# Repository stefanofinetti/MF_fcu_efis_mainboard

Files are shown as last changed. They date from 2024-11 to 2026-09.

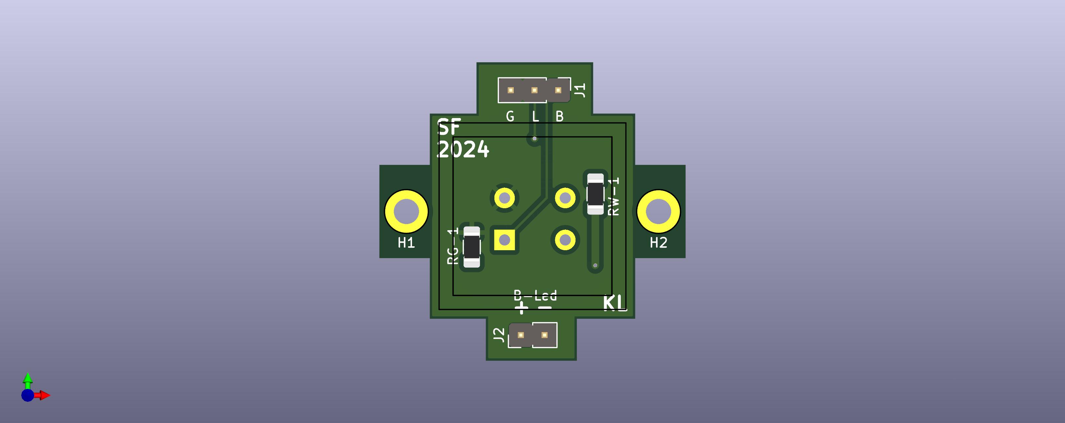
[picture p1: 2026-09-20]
Korry_Large/KorryLargePCB_SMD.jpg

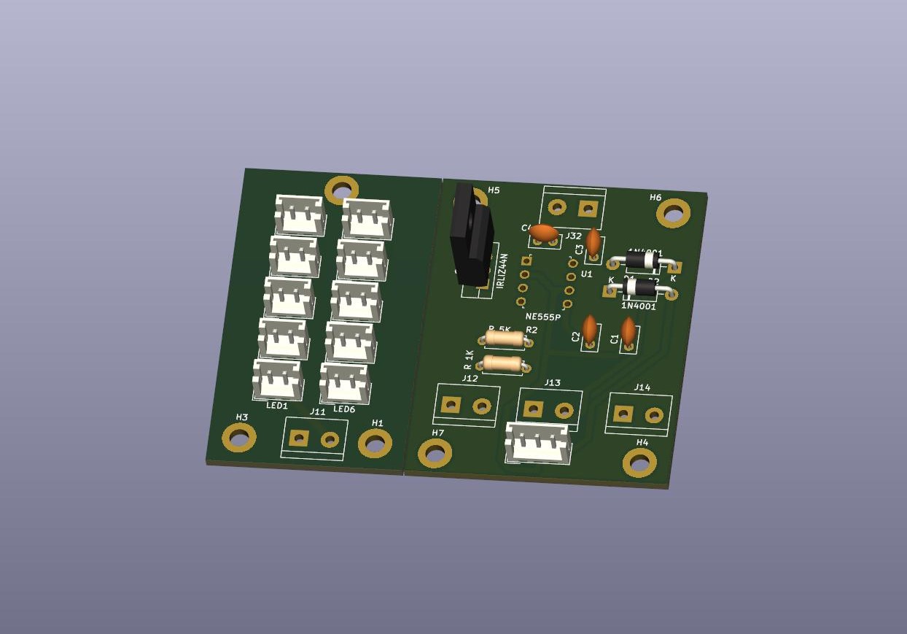
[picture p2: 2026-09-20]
Backlighting_Dimmer/Backlighting_PCB.jpg

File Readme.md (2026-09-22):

# A320 Glareshield — FCU + EFIS

This repository contains the complete glareshield unit: the FCU in the centre
and the two EFIS control panels either side, driven by
[MobiFlight](https://www.mobiflight.com/). The two outer side panels are not
built — three rarely used buttons did not justify the plastic.

The unit sits on a desk, is powered by its own mains adapter and connects to
the PC over USB, so it can be unplugged and moved.

* STL Files for 3D Printing, along with the .3mf files for multicolor printing
* SKP Files from SketchUp, if you want to edit dimensions or change anything
* Kicad files for editing the PCBs or changing components

## Features
- If you decide to not modify anything, you can just print the various 3D components and order the PCBs from JLCPCB.
- You will need a lot of materials, if you open the Kicad Projects you can obtain the BOM directly from them.
- You will need to build your own custom firmware (source provided) or you can use the one in the ZIP file inside the \_dist directory in VsCode Files

---

## Boards

| Folder | Project | Qty | Role |
|---|---|---|---|
| `Mainboard/` | `FCU_Mainboard_v3` | 1 | ATmega2560 + CH340G, 7 OLEDs behind a PCA9548A I²C mux, 4× CD74HC4067 analogue mux for the buttons, 20 annunciator outputs, TPS2115A supply selector. 270 × 100 mm, 2 layers |
| `PSU/` | `9V_Distribution` | 1 | 70 × 80 mm. Two independent regulators off one 9 V input: an LM2596S-5 buck for the backlighting and a P78A05-1000 for the mainboard. See *PSU revision* below |
| `Backlighting_Dimmer/` | `Backlighting_PCB` | 1 | NE555 PWM dimmer, potentiometer controlled, IRLIZ44N low-side switch, three outputs |
| `Backlighting_LEDModule/` | `Backlighting_LEDModule_PCB` | 3 | Passive fan-out: one input → twenty 2-pin outputs. Three of them only to keep the LED strip wiring short |
| `Korry_Large/` | `KorryLargePCB_SMD` | — | Tactile switch + green annunciator LED + white backlight LED |
| `Korry_Small/` | `KorrySmallPCB_SMD` | — | Same, smaller outline |

## Power architecture

```
 mains adapter 9 V / 3 A
        │
        └──► PSU  J1 ──► D1 ──┬──► F2 ──► LM2596S-5 ──► L1 ──┬──► 5 V ──┬──► J2 ─┐
                              │   (2 A)     D2 ◄──┘          │          ├──► J3 ─┤
                              │             catch      C2 ‖ C4          └──► J4 ─┤
                              │                                                  │
                              └──► F3 ──► P78A05-1000 ──► J5 ──► Mainboard J13    │
                                 (0.5 A)   C5‖C6  C7‖C8                  │        │
                                                                     IN1 ▼        │
 PC ──USB──► Mainboard P1 ──► VBUS ──────────────► IN2 ──► U8 TPS2115A            │
   (powered USB3 hub)                                         OUT ──► +5V         │
        │                                                                         │
        └──► 20 × Korry  (green annunciator LED + button)                         │
                   │                                                              │
                   │                            Backlighting_Dimmer ◄─────────────┘
                   │                                    │
                   │                                    └──► 3 × LEDModule
                   └──────────── white backlight LED ◄───────────┘
                                 + 6 LED strip segments
```

Two supply chains that share only ground. The backlighting, which draws the
real current, runs off the mains adapter through the buck. The mainboard takes
whichever of the two is available: `U8` picks the adapter through `J13`
whenever it is plugged in and falls back to USB when it is not — see
*Mainboard selector*.

## Interconnect

**Every cable in the unit is straight through: pin 1 to pin 1.** It was not
always so, and the boards still carry the marks that say which pin is which,
so you can check rather than trust this page.

### Mainboard → Korry (`BTN+LED`, 3-pin)

| pin | Signal | Marked |
|---|---|---|
| 1 | GND | `GND` on the mainboard, `G` on the Korry |
| 2 | annunciator LED, driven by an MCU pin through the 220 Ω on the Korry board | `LED` / `L` |
| 3 | button to GND, read through a CD74HC4067 | `BTN` / `B` |

### LEDModule → Korry (`BK_LED`, 2-pin)

| pin | Signal | Marked |
|---|---|---|
| 1 | +5 V | `+` on the odd row of the LEDModule, `+` on the Korry |
| 2 | switched return, through the 91 Ω on the Korry board | `-` |

### Backlighting_Dimmer → LEDModule (`BOARD_CONN`, screw terminal)

| pin | Signal |
|---|---|
| 1 | +5 V, always present |
| 2 | return, switched to GND by the IRLIZ44N |

The dimmer's three outputs are marked `TO LEDMODULE`, the LEDModule's input
`5V IN`, and both have a `+` and a `-` next to the screws.

### PSU → consumers

`J2`, `J3` and `J4` are three taps on one node, not three independent lines.
There is no per-output fusing. Protection is per *branch*, not per output:
`F2` (2 A) covers everything downstream of the buck, `F3` (0.5 A) covers the
mainboard regulator, and a fault on one cannot take the other down.

## Current budget

Calculated where the resistors are known, estimated elsewhere.

| Load | Rail | Current |
|---|---|---|
| 7 OLEDs | +3V3, from +5V through the AMS1117 | 105–140 mA |
| Green annunciators, 11 lit worst case (220 Ω) | driven by MCU pins | ~130 mA |
| ATmega2560 + CH340G + muxes + power LED | VIN / +5V | ~55 mA |
| **Mainboard total, from USB** | | **290–340 mA** |
| 20 white backlight LEDs (91 Ω) | backlight 5 V | 418 mA |
| 6 LED strip segments, 3528 | backlight 5 V | 360–720 mA |
| **Backlighting total, from the adapter** | | **780–1140 mA** |

The adapter supplies 27 W and the unit uses under 7 W. Nothing is binding any
more: `F2` was the constraint when it was a 1 A part, which derated to under
0.8 A of hold current against the 0.75 A the buck actually draws. At 2 A it
has margin to spare.

## PSU revision

The 9 V distribution board was reworked.

| Change | Why |
|---|---|
| **`D2` added** — 1N5822, cathode on the switch node, anode to ground | A non-synchronous buck has nowhere for the inductor current to go when the switch opens. Without an external diode it freewheels through the substrate diode of the LM2596 itself: roughly 0.4 W of extra dissipation inside the package on top of its own 0.7 W, and substrate injection the part is not specified for. This is why the board works and why it degrades |
| **`C4` added** — 220 µF radial electrolytic in parallel with `C2` | The LM2596 control loop needs some ESR on the output, and `C2` was a ceramic with almost none. `C2` has since become an electrolytic too, so the two now share the job. The RMP V5, same family of design but with electrolytics at its regulator, has never misbehaved |
| **`F2` 1 A → 2 A** (`MF-RHT100` → `MF-RHT200`) | At 1.14 A out the input draws about 0.75 A. Derated for the temperature inside a printed case, a 1 A polyfuse holds under 0.8 A — too close to nuisance tripping. Pads are identical, so the swap costs nothing in layout |
| **Power section re-laid out** | `U4` pin 2, the cathode of `D2` and pin 1 of `L1` now sit on one straight line at y = 64.95, and `C1` sits 4 mm under the VIN pin. The commutation loop went from *nonexistent* to about 4 mm of forward track each side |

### Through-hole where it helps

`D1`, `D2`, `C1` and `C2` were SMD; they are now through-hole. Two of those
four are not a convenience:

* `C1` sits across the 9 V input and needs 25 V of rating. A 1206 MLCC of
  that capacitance does not exist at 25 V, so the part was always going to be
  under-rated and to lose most of its capacitance to DC bias. As a radial
  electrolytic the problem simply goes away.
* `C2` is the buck's output capacitor, and the LM2596 wants some ESR there.
  As a ceramic it had almost none, which is why `C4` was added; as an
  electrolytic it provides it itself.

`D1` and `D2` are 1N5822, 40 V 3 A, which is generous against the ~1 A each
actually carries. `D2` is mounted vertically on a 5.08 mm pitch, shorter than
the 6.8 mm of the SMC it replaces, so the commutation loop got slightly
tighter rather than longer.

Everything in the buck section is now through-hole except `U4`, whose tab
needs the copper pour to dissipate, and the status LEDs with their resistors.
A useful side effect: every ground pad in that section now passes through the
board and reaches both planes on its own, so four stitching vias and their
stubs are gone.

Component spacing was opened up at the same time. Nothing placed by hand is
closer than 2 mm to its neighbour now; the tightest pairs left on the board
are the original LED-and-resistor pairs at 0.66 mm.

### The mainboard branch

The mainboard needs a 5 V source that does not depend on the USB hub. It does
**not** take it from `J2`/`J3`/`J4`: those are one node with the backlighting
on it, PWM-switched by the dimmer's IRLIZ44N in steps of up to 1.1 A. Putting
the MCU and seven OLEDs on that rail would feed them those steps.

Instead a second, independent regulator, tapped from D1's cathode: the reverse
protection is shared, the fuse is not, so a fault on one branch cannot take
down the other. `F3` is 0.5 A for the branch's ~215 mA at 9 V. `U1` is the same
P78A05-1000 module used on RMP V5, with 100 nF + 100 uF each side as there.

The board grew from 50 × 70 to **70 × 80 mm** to make room. The whole
regulator chain lives in the new strip at x 150..170, so the buck section
keeps its original placement and its original routing, and every track stays
on the front: the bottom layer is an uninterrupted ground plane.

All 55 tracks are on the front, so the return current of each loop runs
directly beneath its outward track and the enclosed area stays small.
Stitching vias next to the ground terminals of `C1`, `C2`, `C4` and the anode
of `D2` are tied to their pads by short tracks rather than through the
thermal spokes.

The outline and the four mounting holes did move with the enlargement, so the
printed base has to be reprinted or its brass inserts moved. The positions of
`J1` to `J4` are unchanged, so the wiring loom stays as it is.

## Mainboard selector

`U8` is a TPS2115A power mux: `IN1` takes the clean 5 V from the PSU's `J5`,
`IN2` takes USB `VBUS`, and `OUT` becomes the board's `+5V`. `D0` is tied to ground and `D1` comes from a 100k/100k divider
on the incoming rail, which makes the choice deterministic rather than
"whichever input happens to be higher": the external supply wins whenever it
is above about 4 V, and the board falls back to USB below that.

The part has no body diodes across its switches, so nothing can flow back
into the USB port when the board runs on the adapter. `ILIM` is set to about
0.8 A by `R34`. `STAT` is left unconnected; it is an open-drain output that
goes low on `IN1`, if an indicator is ever wanted.

`P1` pin 1 and `R14`, the D+ pull-up, moved off `+5V` onto the new `VBUS`
net. `JP1`, `VCC` and the ISP path are untouched: `JP1` still chooses whether
`VIN` comes from the board rail or from the programmer.

The symbol lives in `Mainboard/TPS2115A.kicad_sym` with a project-local
`sym-lib-table`, so the repository is self-contained.

Counting tracks as well as footprints, the old 250 mm board had no free
rectangle big enough for the cluster anywhere near the power section, so the
board grew to **270 x 100 mm**: it gains 20 mm on the right and nothing that
already existed moves, apart from the two right-hand mounting holes, which go
from x 265 to x 285. The other five stay put. The 100 mm depth is untouched.

The whole selector sits in that new strip, in a column from `J13` at the top
down through `U8`, `C27` and the divider.

The cluster is routed and the board reports 0 violations, 0 unconnected items
and 0 parity issues.

The three power connections around the selector run at 1 mm, the width their
netclass asks for. They cannot run that wide the whole way: they leave pins
6, 7 and 8 of a TSSOP at 0.65 mm pitch, where the pad itself is only 0.4 mm
tall, so each stays at 0.4 mm for the three to six millimetres it travels
alongside the other two and widens as soon as they diverge. Series resistance
of the three paths, in 35 µm copper:

| Path | |
|---|---|
| `5V_EXT`, `J13` → `U8` pin 8 | 19 mΩ |
| `+5V`, `U8` pin 7 → `C27` | 13 mΩ |
| `VBUS`, `C26` → `U8` pin 6 | 13 mΩ |

The `5V_EXT` spine below y 55 and the tap to `R32` stay at 0.3 mm on purpose:
from there down only the `SEL` divider draws, which is microamps.

## Reading the boards

The silkscreen is meant to be enough on its own: every connector says what
plugs into it and every pin says what it carries, so you can wire the unit
with the boards in front of you and the schematic only for the details.

| Board | What is printed |
|---|---|
| `Mainboard` | the function on each connector (`APPR`, `R_FD`, `HDG_ENC`…) and, next to the pins, `GND` / `LED` / `BTN`, `L` / `R` on the encoders, `VOR` / `ADF`, `hPa` / `inHg`. `J13` carries `5V from PSU` with `GND` and `5V` on its two screws |
| `PSU` | `9V IN` on `J1`, `5V BACKLIGHT` on `J2`–`J4`, `5V MAINBOARD` on `J5`, and a `+` beside the live screw of every terminal |
| `Backlighting_Dimmer` | `5V IN` on the input, `TO LEDMODULE` on the three outputs, `Backlighting POT` on the potentiometer header |
| `Backlighting_LEDModule` | `5V IN` on the input, `+` and `-` beside its screws and beside both output rows |
| `Korry_Large` | `BTN+LED` and `BK_LED` on the two connectors, `G`, `L` and `B` beside pins 1, 2 and 3, `+` and `-` beside the backlight connector and beside each LED on the back, and the two resistor values, 220 and 91, which are otherwise identical parts |
| `Korry_Small` | the same, with `+5` and `L` on the backlight connector and a `+` beside each LED on the back |

Component values live on `F.Silkscreen`, not on `F.Fab`, so they reach the
board. Values are never edited to make a label: where a connector's value is
the name of the terminal block, the value stays where it is and a separate
piece of text carries the meaning.

## Known issues

None open.

## Libraries you will need

All six projects are KiCad 10. Every board reports 0 unconnected items and 0
schematic parity issues, but ERC and DRC still flag missing libraries: the
symbols are embedded in the files so nothing is lost, only the links dangle.
Install these from the Plugin and Content Manager to clear them:

| Library | Used for |
|---|---|
| Alternate KiCad Library | the LED and Schottky footprints: `PCM_LED_AKL`, `PCM_LED_SMD_AKL`, `PCM_Diode_Schottky_AKL`, `PCM_Diode_SMD_AKL` |

That is the only one left. Three others used to be needed and are not any
more. The screw terminals are now `Connector:Screw_Terminal_01x02`, which
ships with KiCad. The two symbols that came from the Digi-Key library, the
NE555 on the dimmer and the tactile switch on `Korry_Large`, now live beside
their own projects:

| File | Symbol |
|---|---|
| `Mainboard/TPS2115A.kicad_sym` | the supply selector |
| `Backlighting_Dimmer/NE555P.kicad_sym` | the timer |
| `Korry_Large/1825910-6.kicad_sym` | the tactile switch |

Those are the symbols the boards were drawn with, not library equivalents,
which matters for the switch: `Switch:SW_Push_Dual` puts its pins in the same
places but numbers them 1-3 and 2-4 where this one numbers them 1-2 and 3-4,
so substituting it would change which pins are shorted inside the button.

Every board has had `Update Footprints from Library` run on it, so the
footprints are the KiCad 10 revisions and no `lib_footprint_mismatch`
remains. If you run it again, untick **Reset text layers and visibilities**
and **Reset text effects**, or every component value goes back to `F.Fab`
and stops being printed.

What each board reports today, with all six at 0 unconnected items and 0
parity issues:

| Board | DRC | ERC |
|---|---|---|
| `Mainboard` | clean | clean |
| `PSU` | clean | clean |
| `Backlighting_Dimmer` | clean | clean |
| `Backlighting_LEDModule` | clean | clean |
| `Korry_Large` | clean | clean |
| `Korry_Small` | clean | clean |

The dimmer carries one excluded violation, recorded in the project file: the
wire-entry drawing inside the `J32` footprint reaches within 0.02 mm of the
board edge, so two hundredths of a millimetre of ink do not get printed.
`J32` cannot move down — `C4` sits 0.04 mm under its courtyard and the
usable window is 10.49 mm tall for a 10 mm body — and the alternative was
editing the library footprint, which is worse than the complaint.

## Gotchas

- **Anything edited outside KiCad leaves the ground pour stale.** The stored
  fill is the one computed before the edit, and until you open the board and
  press `B` DRC invents clearance, hole and solder-mask violations that all
  name `Zone [GND]` and none of which are real. Every board here is committed
  with its zones freshly filled; if you edit the files by script, refill
  before generating production output.
- **If you ever run *Update Footprints from Library*, untick "Reset text
  layers and visibilities" and "Reset text effects".** Without that, every
  component value goes back to `F.Fab` and stops being printed.
- **`F8` in Pcbnew clears `exclude_from_pos_files` on the seven mounting
  holes**, which puts them into the pick-and-place file. Re-check before
  generating production output.
- Three 3D models are missing, and the KiCad package has nothing to stand in
  for them: the two Bourns polyfuses on the `PSU`, the toroid `L1` beside
  them, and `P1` on the mainboard. For the toroid the library carries only
  common-mode ones, which have four pins instead of two; for `P1` the four
  holes sit in a 2 x 2 pattern and every USB-A footprint KiCad ships puts its
  pins in a single row. Everything else on all six boards renders. A few are
  stand-ins of the same package rather than the same part number: the
  crystals use the Wuerth 12SMX, same 7.0 x 5.0 four-pin outline, and the
  P78A05 uses the RECOM R-78E, whose three pins sit on exactly the same
  2.54 mm pitch.
- Some tracks are narrower than their netclass and are meant to be. The two
  0.4102 mm segments on `+3V3` are the breakout from pad 24 of the PCA9548A,
  a 0.65 mm-pitch package whose pad is 0.41 mm tall: it is a dead-end spur
  2.35 mm long carrying the mux's own supply. Same story for the 0.4 mm
  necks at `U8` and the 0.5 mm spur to `U3` pin 24. Widening any of them
  breaks clearance and buys nothing.
- `VIN` has its own netclass with 0.1 mm clearance. Moving it to the `5V`
  class, which uses 0.2 mm, produces about 70 violations against existing
  copper.
- Production files are generated by the
  [Fabrication Toolkit](https://github.com/bennymeg/Fabrication-Toolkit)
  plugin and are not versioned.

---

## Getting Started
### Prerequisites
- Software required:
   * [KiCad](https://www.kicad.org/) — version 10 or later, the projects have been migrated
   * [SketchUp](https://www.sketchup.com)
   * [VsCode]
   * [MobiFlight]

- Any libraries or components used.

### Installation
1. Clone the repository:
   ```bash
   git clone https://github.com/stefanofinetti/MF_A320_Glareshield.git
   ```

## License

This code and all the items are release under GPLv3.0 license. Feel free to use as you wish as long as you redistribute the source code.
It would be nice a mention, though, if you use this work. I invested a good amount of hours just to make it for the amazing MobiFlight community.

Pull requests that fix any of the issues listed above are very welcome.

## Acknowledgements

 This project couldn't have seen the light without the excellent work, and kind support, of [GaGagu](https://github.com/gagagu) and [ElRal](https://github.com/elral). Their work is amazing, so please have a look at their repositories

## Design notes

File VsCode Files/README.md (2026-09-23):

# SF FCU — firmware

MobiFlight custom device that drives the seven OLED displays of an A320
FCU/EFIS panel: the five FCU windows and the two EFIS barometer displays.

Buttons, encoders and LEDs are plain MobiFlight and are configured in the
Connector. They do not go through this firmware.

## What this tracks

The reference is **MobiFlight's own scaffolding**: the project layout,
`platformio.ini`, the build scripts and `MFCustomDevice.*` follow
[MobiFlight/CommunityTemplate](https://github.com/MobiFlight/CommunityTemplate),
and `custom_core_firmware_version` is kept at the core firmware release the
template points to — currently **3.1.4**. `src/` is not in the repository;
`get_CoreFiles.py` clones the core on the first build.

The display code came from Gagagu's
[A320 EFIS/FCU display](https://github.com/gagagu/Mobiflight-A320-Efis-Fcu-Display-with-ESP32)
by way of [elral/MF_FCU_EFIS_OLEDs](https://github.com/elral/MF_FCU_EFIS_OLEDs)
v1.0.1. `FCU_EFIS.cpp`, `OLEDInterface.h` and the fonts are theirs. Following
elral is *not* a goal — following the MobiFlight core is.

## What differs from the template

| | |
|---|---|
| Device type | `SF_FCU`, so it installs alongside the upstream one |
| EFIS channels | left and right are the other way round from upstream |
| `SERIAL_RX_BUFFER_SIZE` | 256, not the template's 96 — see below |
| Targets | Mega only |

### Multiplexer channels

The seven displays hang off a PCA9548A, one display per channel:

| Channel | Display |
|---|---|
| 0 | EFIS right — barometer |
| 1 | EFIS left — barometer |
| 2 | SPD / MACH |
| 3 | HDG / TRK |
| 4 | HDG-V/S / TRK-FPA annunciator |
| 5 | ALT |
| 6 | V/S — FPA |

The channel numbers live in `FCU_EFIS.h`. Change them there if the displays
are wired to different channels.

### Serial receive buffer

A display update blocks the loop for roughly 28 ms — 5 ms of `delay()` for the
multiplexer switch plus a 1 KB frame at 400 kHz. At 115200 baud more than 300
bytes can arrive in that window, so the template's 96-byte receive buffer
would drop characters. Do not lower it.

### Footprint

The ATmega2560 has 8 KB of RAM and MobiFlight reserves most of it up front:
1600 bytes for the device arena (`MF_MAX_DEVICEMEM`) and 1000 for the input
names (`MEMLEN_NAMES_BUFFER`). Those two are sized for the Connector config,
not for this code, and are the wrong place to economise.

What this project does instead:

* **`build_unflags` turns off the device families the panel cannot have** —
  segment displays, character LCD, steppers, servos, analog inputs and both
  shift registers. Input multiplexers stay on; the panel uses them. Buttons,
  encoders and outputs are core and always present. This is worth 181 bytes
  of RAM and about 14 KB of flash. To get one back, delete its line.
* **No `String` anywhere.** The values from the Connector live in fixed
  buffers, so a redraw allocates nothing and the heap cannot fragment. The
  only allocation left in the whole firmware is Adafruit's 1 KB frame buffer,
  taken once at startup.

Static RAM actually rose by 18 bytes when the `String`s went, because nine
6-byte objects became nine 8-byte buffers. The point was never the 18 bytes:
it was that each of those objects also held a heap block, and three more were
allocated and freed on every single redraw.

## I2C address and display type

The custom device takes the address of the PCA9548A, which the multiplexer's
A0/A1/A2 pins set: all low is 0x70.

The address also picks the display driver, which is easy to miss:

* **even** address (0x70) → **SH1106**
* **odd** address (0x71) → **SSD1306**

So an SSD1306 needs the multiplexer strapped to an odd address and the custom
device set to match. The shipped `SF FCU.mfmc` is set to 0x70, i.e. SH1106.

## Building

PlatformIO installed through the VS Code extension does not put `pio` on the
PATH. Either open a terminal from the PlatformIO toolbar, or call it by its
full path, `%USERPROFILE%\.platformio\penv\Scripts\pio.exe`.

```
pio run -e SF_FCU_mega
```

That produces version `0.0.1`. For a real one set `VERSION` — the build
stamps it into both the firmware filename and `board.json`, which have to
agree or MobiFlight will not find the firmware. The version has to be an
environment variable, so the syntax differs per shell:

```
rem cmd.exe
rmdir /s /q _build _dist
set "VERSION=1.1.0" && pio run -e SF_FCU_mega
```

```
# PowerShell
Remove-Item -Recurse -Force _build, _dist -ErrorAction SilentlyContinue
$env:VERSION = "1.1.0"; pio run -e SF_FCU_mega
```

```
# bash, and what the GitHub workflow uses
rm -rf _build _dist
VERSION=1.1.0 pio run -e SF_FCU_mega
```

Deleting `_build` and `_dist` first is not optional: `copy_fw_files.py` only
stamps the version into `board.json` when `_build/` does not yet exist, so a
leftover folder ships the previous version's json.

The result is an installable ZIP in `_dist/`. Extract it into the `Community`
folder of your MobiFlight installation, then flash from the Connector.

`documents/` holds Gagagu's original drawings, kept for reference.

## Known gaps, inherited from upstream

* MessageID −1 (Connector closing) and −2 (power saving, after the 600 s in
  the `.mfmc`) are not handled, so the displays keep showing the last values
  instead of going dark. On OLEDs that is a burn-in risk.
* The Mach zero-padding in `updateDisplayFcuSpd()` writes past the end of the
  `String` and silently does nothing.
* The zero-padding elsewhere relies on `String::operator[]` returning a zeroed
  dummy when read out of range. It works, but on an implementation detail.

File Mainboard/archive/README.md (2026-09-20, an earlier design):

# Archived schematics

Files kept here are **not part of the FCU_Mainboard_v3 design**. They are not
referenced by the root sheet and are excluded from ERC, DRC, the netlist and
the BOM. Nothing in the fabricated board depends on them.

## backlighting.kicad_sch

Panel backlighting for the FCU + EFIS unit. It is **not connected to the
mainboard**: the backlight has its own dedicated circuitry and is not driven by
MobiFlight, so brightness cannot be controlled from the simulator.

Kept because the design may be revisited if backlight control is ever brought
under MobiFlight. If that happens it will be redesigned from scratch rather
than wired into the current board, so treat this file as a reference for the
existing circuit, not as a starting point.

## Removed, recoverable from git history

Two more orphan sheets were deleted rather than archived, both superseded
leftovers from v2:

- `EFIS.kicad_sch` — the v2 combined EFIS sheet. Its reference designators
  clash with the live sheets while meaning something else (J16 was
  `L_EFIS_FD`, it is now `R_FD`), and its global labels use an older naming
  scheme (`L_EFIS_FD_BTN`, `L_EFIS_RNG_160`, ...) that no longer exists.
  Superseded by `efis_left.kicad_sch` and `efis_right.kicad_sch`.
- `multiplexers.kicad_sch` — U3/U4 as CD74HC4067 breakout modules. The board
  now uses bare `74xx:CD74HC4067M` in SOIC-24W.

Both were removed in the commit that created this file; `git log --diff-filter=D
-- "Kicad Files/EFIS.kicad_sch"` will find them.

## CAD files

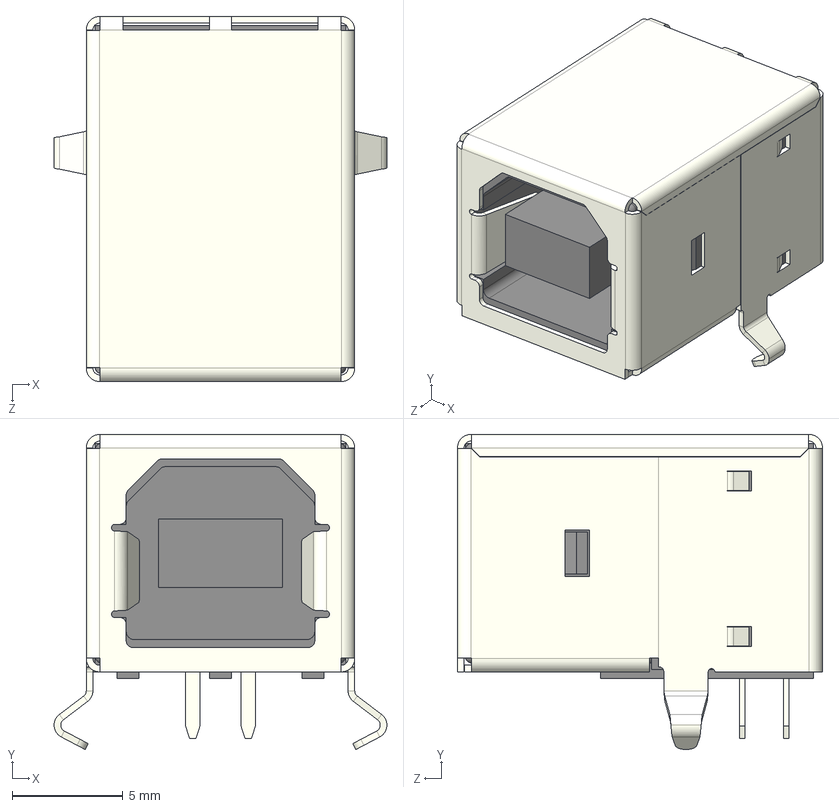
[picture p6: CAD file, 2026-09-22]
Mainboard/3dmodels/USB_B_SameSky_UJ2-BH-1-TH.step
15.0 x 14.2 x 16.5 mm

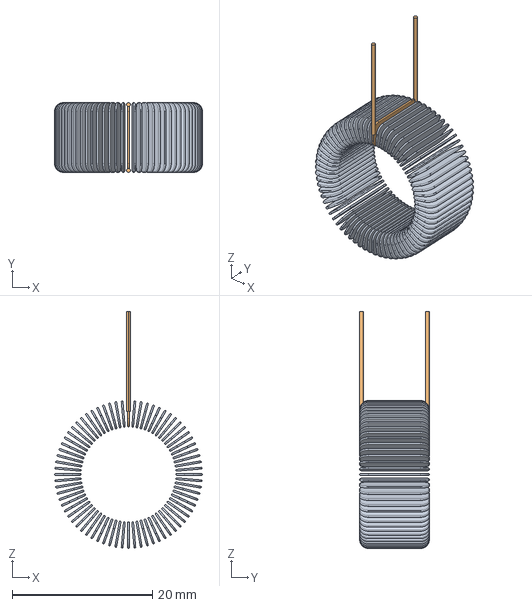
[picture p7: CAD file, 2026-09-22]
PSU/3dmodels/2100LL-1R0-V-RC.step
21.1 x 9.96 x 33.8 mm

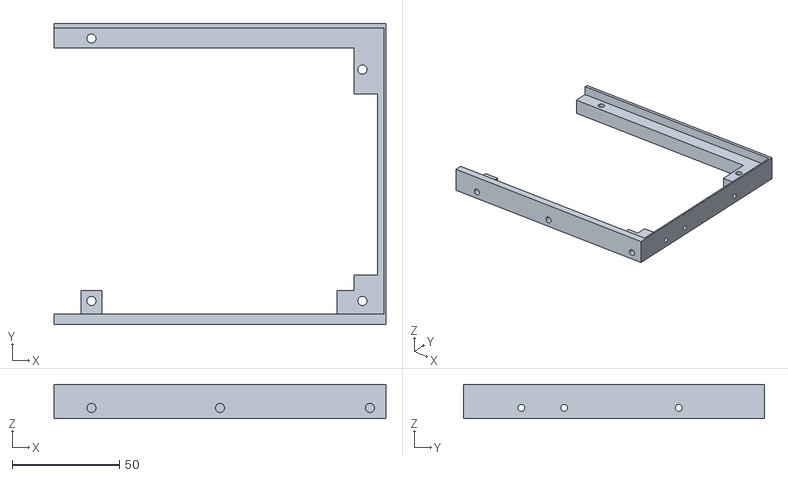
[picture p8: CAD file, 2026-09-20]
STL Files/Black/FCU_FRAME_RIGHT.stl
155.0 x 140.5 x 16.0

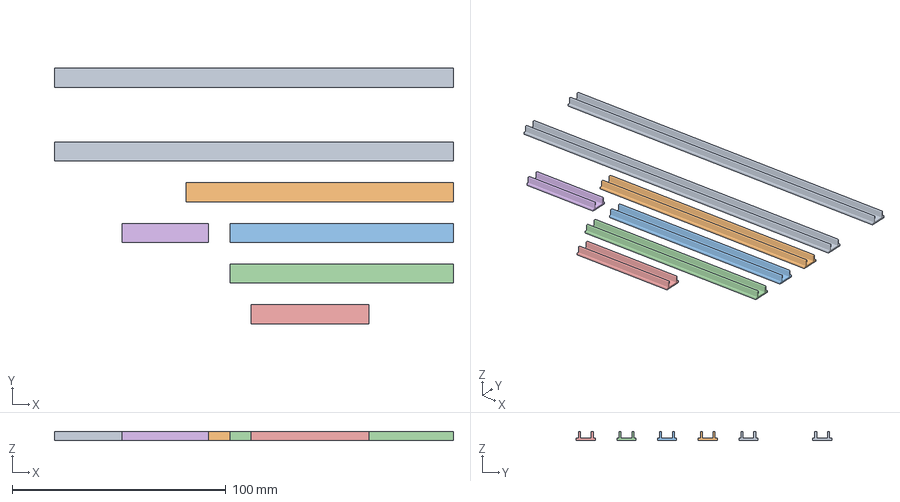
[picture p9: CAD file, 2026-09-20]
STL Files/FCU_LED_RAILS_COVER.3mf
186.5 x 119.5 x 4.00 mm
EFIS_LEFT_LED_RAILS_COVER.stl
FCU_LED_RAILS_COVER.stl_5
FCU_LED_RAILS_COVER.stl_3
FCU_LED_RAILS_COVER.stl_4
FCU_LED_RAILS_COVER.stl_1
FCU_LED_RAILS_COVER.stl_2

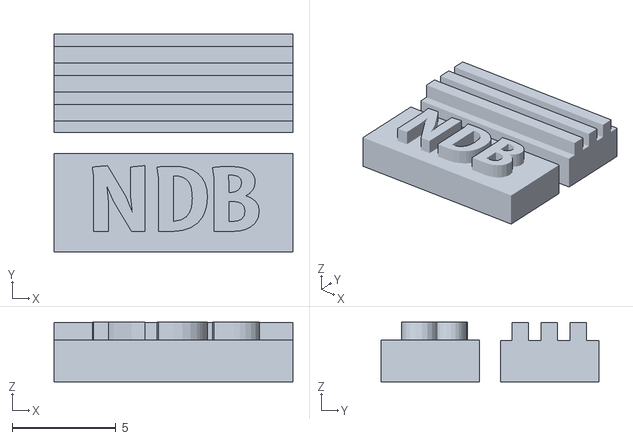
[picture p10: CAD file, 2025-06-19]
STL Files/Korry_19x16/NDB_transparent_V5.stl
11.5 x 10.5 x 2.88

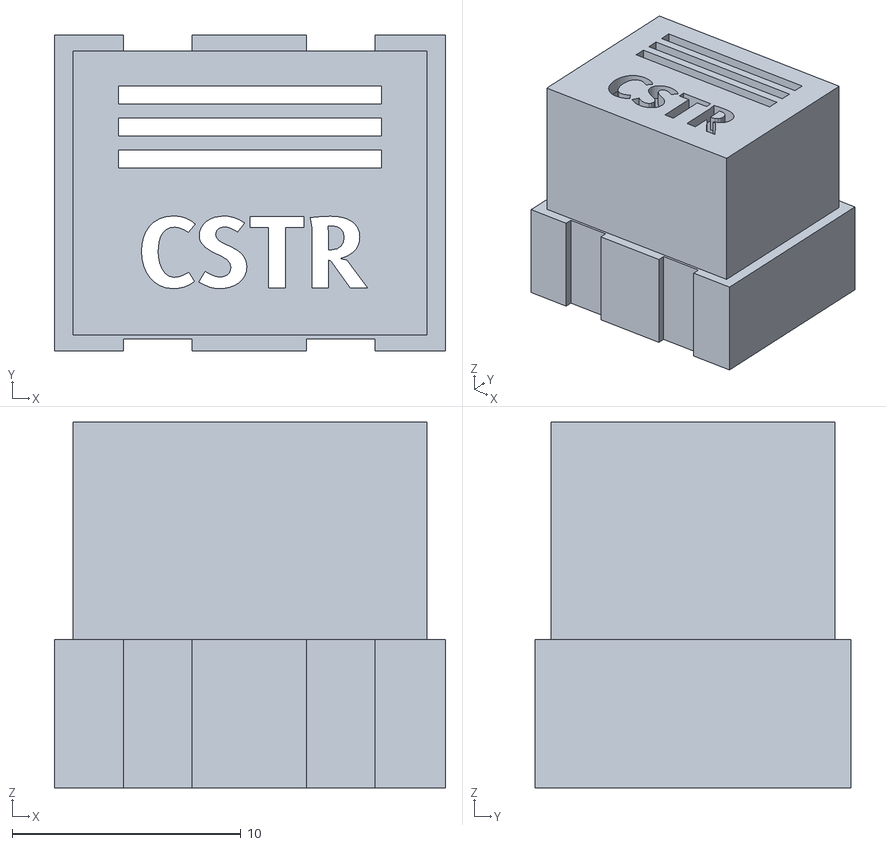
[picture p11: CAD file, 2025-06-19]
STL Files/Korry_19x16/V5/CSTR_BLACK.stl
17.1 x 13.8 x 16.0

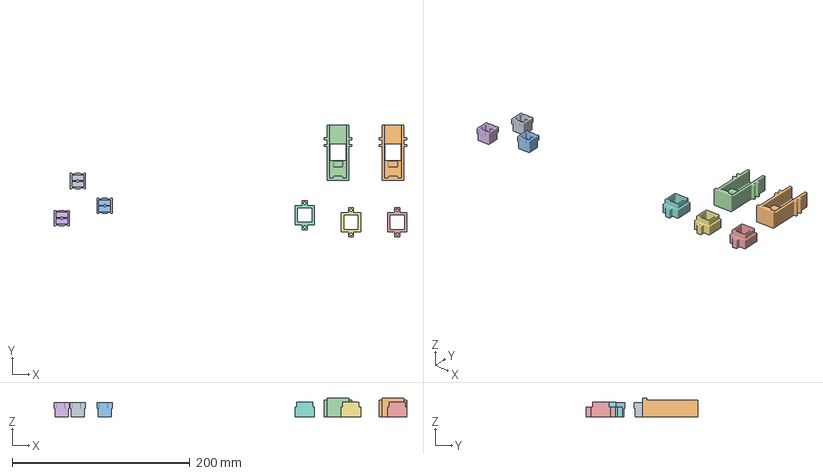
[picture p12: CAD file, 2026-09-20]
STL Files/Korry_19x19/Korry19x19_button.3mf
397.0 x 125.8 x 21.2 mm
AP1_button
Rotary_ALT_BARO_Outer_case.stl x 2
AP2_button
Korry19x19_case_v5.stl x 3
AT_button

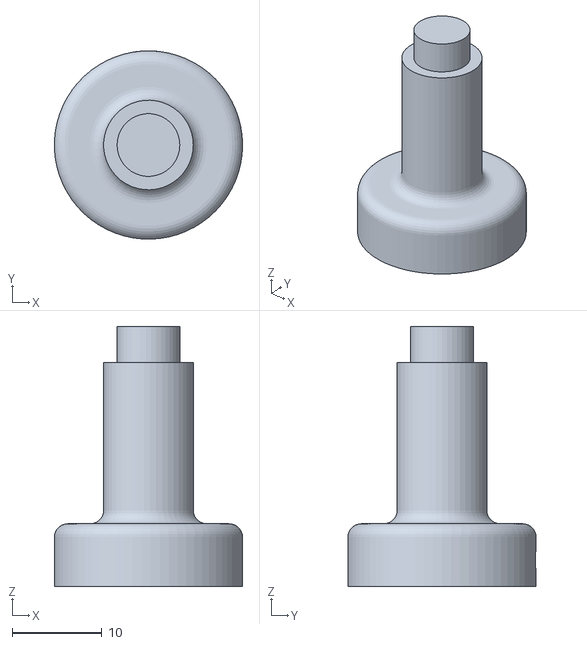
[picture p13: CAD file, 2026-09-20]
STL Files/Rotaries/SpeedKnob_Base.stl
21.0 x 21.0 x 29.0

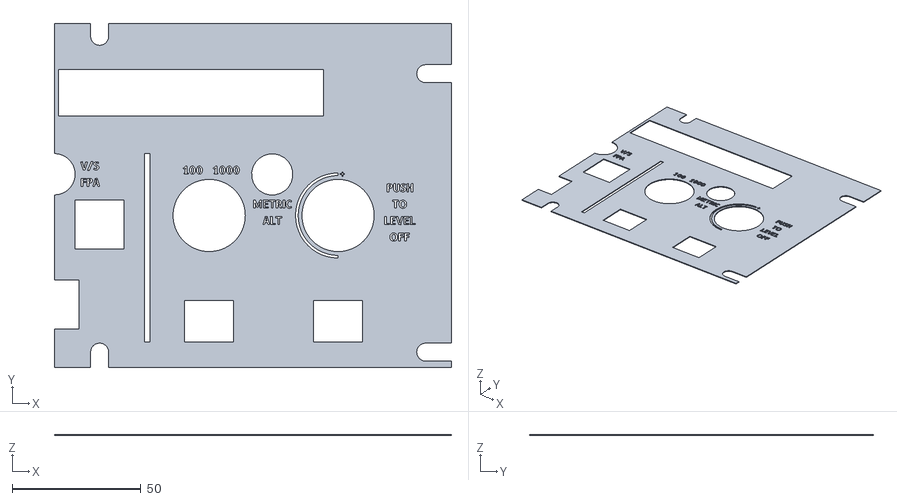
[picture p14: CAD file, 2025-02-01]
STL Files/V4C/FCU_RIGHT_BLACK.stl
154.0 x 133.5 x 0.42

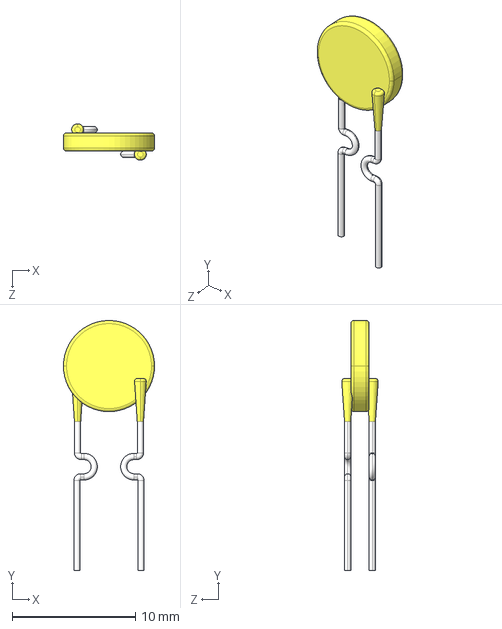
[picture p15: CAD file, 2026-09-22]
PSU/3dmodels/Fuse_Bourns_MF-RHT050.step
7.40 x 20.3 x 2.96 mm

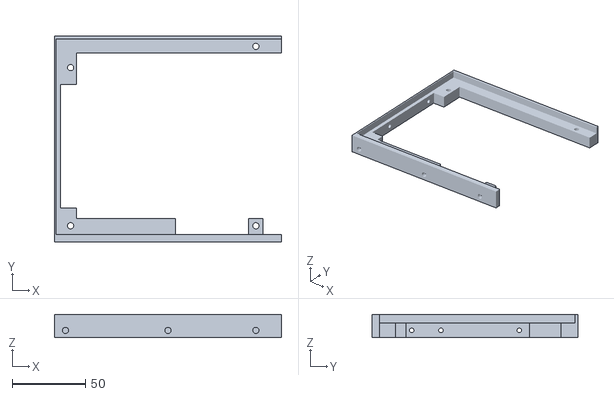
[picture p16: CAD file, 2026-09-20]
STL Files/Black/FCU_FRAME_LEFT.stl
155.0 x 140.5 x 16.0

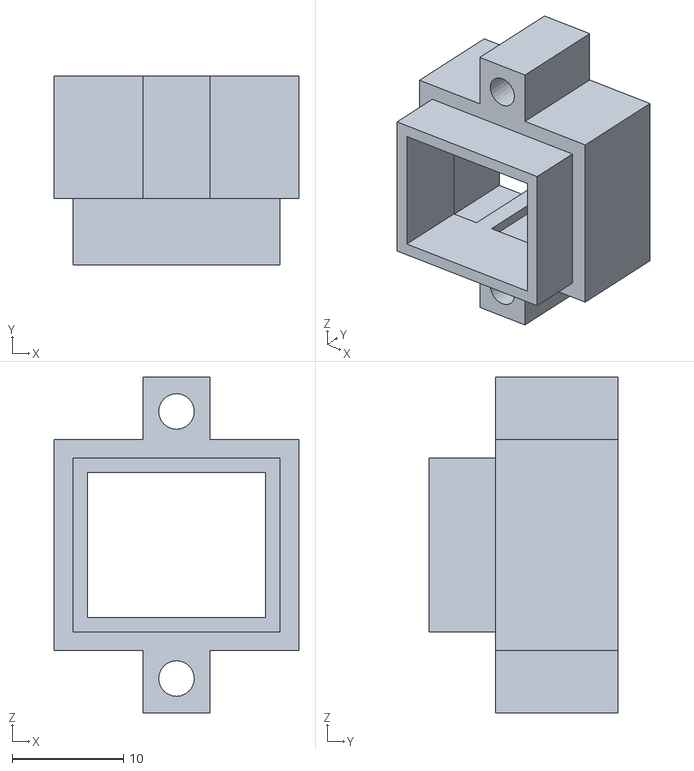
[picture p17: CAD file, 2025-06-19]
STL Files/Korry_19x16/Korry19x16_case_v5.stl
22.0 x 17.0 x 30.2

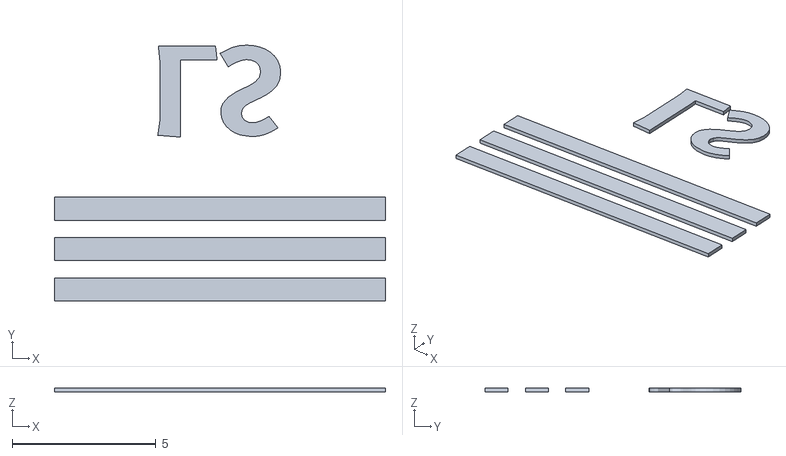
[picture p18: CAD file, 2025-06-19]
STL Files/Korry_19x16/V5/LS_WHITE.stl
11.5 x 8.88 x 0.14

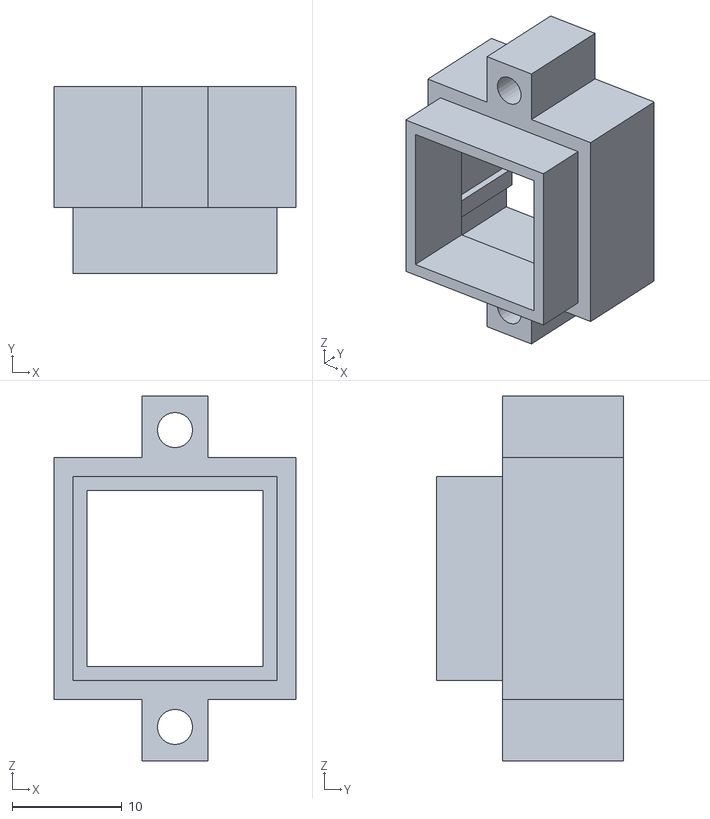
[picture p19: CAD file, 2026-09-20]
STL Files/Korry_19x19/Korry19x19_case_v5.stl
22.0 x 17.0 x 33.2

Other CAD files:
STL Files/PushPullBlackFlipper.stl
STL Files/Rotaries/VSpeedKnob_Base.stl
STL Files/V4C/FCU_LEFT.3mf
PSU/3dmodels/Fuse_Bourns_MF-RHT200.step
3D Files/EFIS/EFIS_V4b_RIGHT.skp
3D Files/EFIS/EVIS_V4b_Backlighting_Support.skp
3D Files/FCU/FCU_12mm_button_caps.skp
3D Files/FCU/FCU_12mm_button_case.skp
3D Files/FCU/FCU_12mm_button_keeper.skp
3D Files/FCU/FCU_V4b.skp
3D Files/FCU/FCU_V4b_LEFT.skp
3D Files/FCU/FCU_V4b_RIGHT.skp
3D Files/FCU/FCU_V4c.skp
3D Files/Frame/EFIS_OLED_MASK.skp
3D Files/Frame/EFIS_TOP_LEFT.skp
3D Files/Frame/EFIS_TOP_RIGHT_LED.skp
3D Files/Frame/EFIS_V4_LEFT_FRAME.skp
3D Files/Frame/EFIS_V4_RIGHT_FRAME.skp
3D Files/Frame/FCU_TOP_CENTER.skp
3D Files/Frame/FCU_TOP_LEFT.skp
3D Files/Frame/FCU_TOP_RIGHT.skp
3D Files/Frame/FCU_UNIT_BACK_LEFT.skp
3D Files/Frame/FCU_UNIT_BACK_LEFT_PSU.skp
3D Files/Frame/FCU_UNIT_BACK_RIGHT.skp
3D Files/Frame/FCU_UNIT_BACK_RIGHT_USB.skp
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

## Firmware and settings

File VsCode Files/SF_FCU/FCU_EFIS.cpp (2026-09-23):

#include "FCU_EFIS.h"
#include <Fonts/FreeSans18pt7b.h>
#include <Fonts/FreeSans9pt7b.h>
#include "Fonts/FreeSans8pt7b.h"
#include "Fonts/DSEG7Classic_Regular15pt7b.h"
#include "Fonts/DSEG7Classic_Regular20pt7b.h" //https://github.com/keshikan/DSEG and https://rop.nl/truetype2gfx/
#include "Fonts/DSEG7Classic_Regular22pt7b.h"

/* **********************************************************************************
    The values arrive from the Connector as strings and are kept in fixed buffers
    rather than String objects: nothing is allocated at runtime, so the heap cannot
    fragment while the displays are being redrawn.

    setValue() zero fills whatever follows the string, which matters: the padding
    code below reads past the end of a value on purpose and expects to find 0
    there. That was what Arduino's String did, and it is reproduced here.
********************************************************************************** */
#define VALUE_LEN 8

static void setValue(char *dst, const char *src)
{
    strncpy(dst, src, VALUE_LEN - 1);
    dst[VALUE_LEN - 1] = 0x00;
}

// Efis left
uint8_t efisLeftBaroMode              = 0x00;
uint8_t efisLeftBaroSelect            = 0x00;
char    efisLeftBaroValueHpa[VALUE_LEN] = "1013";
char    efisLeftBaroValueHg[VALUE_LEN]  = "2992";

// Efis right
uint8_t efisRightBaroMode              = 0x00;
uint8_t efisRightBaroSelect            = 0x00;
char    efisRightBaroValueHpa[VALUE_LEN] = "1013";
char    efisRightBaroValueHg[VALUE_LEN]  = "2992";

// FCU Speed
uint8_t fcuSpeedManagedMode        = 0x00;
char    fcuSpeedValue[VALUE_LEN]   = "000";
uint8_t fcuSpeedMode               = 0x00;

// FCU Hdg
uint8_t fcuHdgManagedMode      = 0x00;
char    fcuHdgValue[VALUE_LEN] = "000";

// FCU Trk Mode
uint8_t fcuTrkMode = 0x00;

// FCU Alt
uint8_t fcuAltManagedMode      = 0x00;
char    fcuAltValue[VALUE_LEN] = "00000";

// FCU VS
uint8_t fcuVsManagedMode          = 0x00;
char    fcuVsValue[VALUE_LEN]     = "00000";
char    fcuVsValueFpa[VALUE_LEN]  = "-0.0";

// light test switch
uint8_t lightTestOn = 0x00;

FCU_EFIS::FCU_EFIS()
{
    _initialised = false;
}

void FCU_EFIS::attach(uint8_t addrI2C)
{
    _addrI2C = addrI2C;
    Wire.begin();
    Wire.setClock(400000);
    void *mem = MF_ALLOC_TYPE(OLEDInterface, 1);
    if (!mem) {
        // Error Message to Connector
        cmdMessenger.sendCmd(kStatus, F("Custom Device does not fit in Memory"));
        return;
    }
    // an odd address selects the SSD1306 driver, an even one the SH1106
    if (_addrI2C & 0x01) {
        oled = new (mem) OLEDInterface(SSD1306);
    } else {
        oled = new (mem) OLEDInterface(SH1106);
    }
    _initialised = true;
}

void FCU_EFIS::begin()
{
    if (!_initialised)
        return;

    //**********************************************
    // EFIS left
    //**********************************************
    setTCAChannel(TCA9548A_CHANNEL_EFIS_LEFT);
    oled->begin(SCREEN_ADDRESS, true); // Address 0x3C default
    updateDisplayEfisLeft();

    //**********************************************
    // EFIS right
    //**********************************************
    setTCAChannel(TCA9548A_CHANNEL_EFIS_RIGHT);
    oled->begin(SCREEN_ADDRESS, true); // Address 0x3C default
    updateDisplayEfisRight();

    //**********************************************
    // FCU SPD
    //**********************************************
    setTCAChannel(TCA9548A_CHANNEL_FCU_SPD);
    oled->begin(SCREEN_ADDRESS, true); // Address 0x3C default
    updateDisplayFcuSpd();

    //**********************************************
    // FCU HDG
    //**********************************************
    setTCAChannel(TCA9548A_CHANNEL_FCU_HDG);
    oled->begin(SCREEN_ADDRESS, true); // Address 0x3C default
    updateDisplayFcuHdg();

    //**********************************************
    // FCU HDG and V/S or TRK and FPA.
    //**********************************************
    setTCAChannel(TCA9548A_CHANNEL_FCU_FPA);
    oled->begin(SCREEN_ADDRESS, true); // Address 0x3C default
    updateDisplayFcuFpa();

    //**********************************************
    // FCU ALT
    //**********************************************
    setTCAChannel(TCA9548A_CHANNEL_FCU_ALT);
    oled->begin(SCREEN_ADDRESS, true); // Address 0x3C default
    updateDisplayFcuAlt();

    //**********************************************
    // FCU Vs
    //**********************************************
    setTCAChannel(TCA9548A_CHANNEL_FCU_VS);
    oled->begin(SCREEN_ADDRESS, true); // Address 0x3C default
    updateDisplayFcuVs();
}

void FCU_EFIS::detach()
{
    if (!_initialised)
        return;
    _initialised = false;
}
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

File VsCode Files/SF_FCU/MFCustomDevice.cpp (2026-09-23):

#include "MFCustomDevice.h"
#include "commandmessenger.h"
#include "allocateMem.h"
#include "MFEEPROM.h"
#if defined(HAS_CONFIG_IN_FLASH)
#include "MFCustomDevicesConfig.h"
#else
const char CustomDeviceConfig[] PROGMEM = {};
#endif

extern MFEEPROM MFeeprom;

/* **********************************************************************************
    The custom device pins, type and configuration is stored in the EEPROM.
    While loading the config the adresses in the EEPROM are transferred to the
    constructor. Within the constructor you have to copy the EEPROM content to a
    buffer and evaluate it. The buffer is used for all 3 types (pins, type,
    configuration), so do it step by step.

    This device takes one value only, the I2C address of the multiplexer, but the
    type string "SF_FCU" passes through the same buffer.
********************************************************************************** */
#define MEMLEN_STRING_BUFFER 40

// reads a string from EEPROM or Flash at given address which is '.' terminated and saves it to the buffer
bool MFCustomDevice::getStringFromMem(uint16_t addrMem, char *buffer, bool configFromFlash)
{
    char     temp    = 0;
    uint8_t  counter = 0;
    uint16_t length  = MFeeprom.get_length();
    do {
        if (configFromFlash) {
            temp = pgm_read_byte_near(CustomDeviceConfig + addrMem++);
            if (addrMem > sizeof(CustomDeviceConfig))
                return false;
        } else {
            temp = MFeeprom.read_byte(addrMem++);
            if (addrMem > length)
                return false;
        }
        buffer[counter++] = temp;              // save character and locate next buffer position
        if (counter >= MEMLEN_STRING_BUFFER) { // nameBuffer will be exceeded
            return false;                      // abort copying to buffer
        }
    } while (temp != '.');      // reads until limiter '.' and locates the next free buffer position
    buffer[counter - 1] = 0x00; // replace '.' by NULL, terminates the string
    return true;
}

MFCustomDevice::MFCustomDevice()
{
    _initialized = false;
}

/* **********************************************************************************
    Within the connector pins, a device name and a config string can be defined.
    These informations are stored in the EEPROM or Flash like for the other devices.
    While reading the config from the EEPROM or Flash this function is called.
    It is the first function which will be called for the custom device.
    If it fits into the memory buffer, the constructor for the customer device
    will be called.
********************************************************************************** */

void MFCustomDevice::attach(uint16_t adrPin, uint16_t adrType, uint16_t adrConfig, bool configFromFlash)
{
    if (adrPin == 0) return;

    char   *params, *p = NULL;
    char    parameter[MEMLEN_STRING_BUFFER];
    uint8_t addrI2C;

    /* **********************************************************************************
        Read the Type from the EEPROM or Flash, copy it into a buffer and evaluate it.
        The string does NOT get stored as this would need a lot of RAM, instead a
        variable is used to store the type.
    ********************************************************************************** */
    getStringFromMem(adrType, parameter, configFromFlash);
    // "GAGAGU_FCU-EFIS" is what boards flashed with the upstream firmware carry
    // in their EEPROM. Accepting it too means this firmware drops straight onto
    // such a board without rebuilding its configuration first.
    if (strcmp(parameter, "SF_FCU") == 0 || strcmp(parameter, "GAGAGU_FCU-EFIS") == 0)
        _customType = FCU_EFIS_DEVICE;

    if (_customType == FCU_EFIS_DEVICE) {
        /* **********************************************************************************
            Check if the device fits into the device buffer
        ********************************************************************************** */
        void *mem = MF_ALLOC_TYPE(FCU_EFIS, 1);
        if (!mem) {
            // Error Message to Connector
            cmdMessenger.sendCmd(kStatus, F("Custom Device does not fit in Memory"));
            // nothing was constructed, so do not let detach() dereference the pointer
            _customType = 0;
            return;
        }
        /* **********************************************************************************************
            Read the pins from the EEPROM or Flash, copy them into a buffer.
            '"isI2C": true' is set in the device.json file, so the first value is the I2C
            address of the PCA9548A the seven displays hang off.
        ********************************************************************************************** */
        getStringFromMem(adrPin, parameter, configFromFlash);
        params  = strtok_r(parameter, "|", &p);
        addrI2C = atoi(params);

        /* **********************************************************************************
            The config string is not used by this device, so it is not read here.
        ********************************************************************************** */

        _my_FCU_EFIS = new (mem) FCU_EFIS();
        _my_FCU_EFIS->attach(addrI2C);
        _my_FCU_EFIS->begin();
        _initialized = true;
    } else {
        cmdMessenger.sendCmd(kStatus, F("Custom Device is not supported by this firmware version"));
    }
}

/* **********************************************************************************
    The custom devives gets unregistered if a new config gets uploaded.
    Keep it as it is, mostly nothing must be changed.
    It gets called from CustomerDevice::Clear()
********************************************************************************** */
void MFCustomDevice::detach()
{
    _initialized = false;
    if (_customType == FCU_EFIS_DEVICE) {
        _my_FCU_EFIS->detach();
    }
}

/* **********************************************************************************
    Within in loop() the update() function is called regularly.
    Within the loop() you can define a time delay where this function gets called
    or as fast as possible. See comments in loop().
    It is only needed if you have to update your custom device without getting
    new values from the connector.
    It gets called from CustomerDevice::update()
********************************************************************************** */
void MFCustomDevice::update()
{
    if (!_initialized) return;

    if (_customType == FCU_EFIS_DEVICE) {
        _my_FCU_EFIS->update();
    }
}
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

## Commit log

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2025-02-01 Fixed a serious error in the pcb design. I2C had a wrongly connected path between L an R EFIS OLEDs. Also added a dipswitch to select I2C address
    [01_FCU_V4b_LEFT_transparent.stl, 01_FCU_V4b_RIGHT_transparent.stl, 02_FCU_V4b_LEFT_black.stl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]
2025-02-01 New routing with thicker 5V and 3V lines, better arrangement. Removed the useless RX and TX leds, they weren't really working as intended.
    [FCU_Mainboard_v3.kicad_pcb, FCU_Mainboard_v3.kicad_sch, pwr_conn.kicad_sch]
2025-06-19 Complete rework of panels to be printed facedown. Important: change the order of the colors as Grey, White, Black, Transparent if using a Bambulab P1S/X1C ALso corrected some issue with the PCB (opti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
    [01_EFIS_V4b_LEFT_transparent.stl, 01_EFIS_V4b_RIGHT_transparent.stl, 01_FCU_V4b_LEFT_transparent.stl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]
2025-06-19 Tracked missing files
    [01_EFIS_LEFT_V4b.3mf, 05_FCU_V4b_LEFT_RAILS_white.stl, 05_FCU_V4b_RIGHT_RAILS_white.stl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]
2025-06-21 New stl files for LEFT EFIS. New 3D Design for push pull elements and for alt/metric and similar buttons. Others to come in the next few weeks
    [01_EFIS_V4b_LEFT_firstlayer_transparent.stl, AP1_button.stl, AP1_transparent.stl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]
2026-09-20 Fix ERC errors, add VIN netclass, correct P1 value
    Housekeeping pass after migrating to KiCad 10. No change to the copper
    layout or to the netlist: DRC still reports 0 unconnected items and 0
    schematic parity issues.
    ERC: 10 violations / 2 errors -> 4 violations / 0 errors
    - Remove PWR_FLAG #FLG01 (+5V) and #FLG02 (GND). Both were redundant:
    the USB_B symbol of P1 already declares VBUS and GND as power output
    pins, which is what triggered the pin_to_pin errors. The flags on VIN
    and VCC are kept, those rails are fed by passive connectors (JP1 and
    the ISP header) and would otherwise read as undriven.
    - Remove a dangling no-connect flag in the root sheet.
    - Add a dedicated VIN netclas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
    [FCU_Mainboard_v3.kicad_pcb, FCU_Mainboard_v3.kicad_sch, efis_left.kicad_sch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]
2026-09-20 Archive backlighting sheet, drop two superseded v2 orphans
    None of these files were referenced by the root sheet, so ERC, DRC, the
    netlist and the BOM are unchanged: still 0 errors, 0 unconnected items,
    0 schematic parity issues.
    - Move backlighting.kicad_sch to archive/. The FCU + EFIS backlight has
    its own dedicated circuitry, is not wired to the mainboard and is not
    driven by MobiFlight, so it cannot be dimmed from the simulator. Kept
    as a reference in case backlight control is ever brought under
    MobiFlight, which would mean a redesign rather than a port.
    - Delete EFIS.kicad_sch. The v2 combined EFIS sheet, superseded by
    efis_left/efis_right. Its designators clash with the live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
    [EFIS.kicad_sch, backlighting.kicad_sch, multiplexers.kicad_sch]
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2026-09-20 Updating Korry design and Push/Pull Mechanics
    Also stop tracking SketchUp auto-backups. A .skb is a near-copy of the
    .skp from the previous save (FCU_UNIT.skb alone is 28.8 MB) and, being
    binary, git stored a whole new blob every time one was touched: 18 files
    accounting for roughly 67 MB of the 181 MB repository. They are removed
    from the index with git rm --cached and stay on disk; a root .gitignore
    keeps them out from now on.
    [AP1_button.stl, AP2_button.stl, AT_button.stl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]
2026-09-20 Migrate project files to KiCad 10 format
    Opened and saved in KiCad 10, which rewrites the files on load:
    schematics 20241229 -> 20260306, board 20241229 -> 20260206. The project
    no longer opens in KiCad 9.
    The diff is large but carries no design change. Verified by exporting the
    netlist from the previous revision and from the converted files and
    comparing them:
    nets 198 -> 198, none renamed, no node moved
    components 131 -> 131, no value or footprint changed
    ERC 4 warnings, 0 errors (unchanged)
    DRC 122 violations (unchanged), 0 unconnected,
    0 schematic parity issues
    The 120 lib_footpri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
    [FCU_Mainboard_v3.kicad_pcb, FCU_Mainboard_v3.kicad_sch, efis_left.kicad_sch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]
2026-09-20 Update schematic symbols from KiCad 10 libraries
    Ran Update Symbols from Library on all sheets, then repaired two side
    effects of it. ERC is now clean: 4 warnings -> 0 violations.
    The only change to the netlist in the whole project is the USB shield
    pin, which KiCad renamed in both the symbol and the footprint:
    net GND: P1 pin '5' -> P1 pin 'SH'
    Everything else is byte-for-byte equivalent electrically: 198 nets, 131
    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
    [FCU_Mainboard_v3.kicad_sch, efis_left.kicad_sch, efis_right.kicad_sch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]
2026-09-20 Update board footprints from KiCad 10 libraries
    Ran Update Footprints from Library followed by Update PCB from Schematic.
    Board footprints now match the KiCad 10 libraries with zero electrical
    differences across all 131 components.
    DRC 122 violations -> 3 (120 lib_footprint_mismatch -> 0)
    ERC 4 warnings -> 0
    unconnected items -> 0
    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
    [FCU_Mainboard_v3.kicad_pcb, FCU_Mainboard_v3.kicad_sch, pwr_conn.kicad_sch]
2026-09-20 Regenerate production files, record new Fabrication Toolkit options
    Reinstalled the Fabrication Toolkit plugin on KiCad 10 and regenerated
    the gerbers, BOM, position and designator files, which were still the
    March 2025 set and no longer matched the board.
    The only versioned change is the plugin options file, where the newer
    release added three keys (ARCHIVE_NAME, OPEN BROWSER, BACKUP_OPT). The
    existing settings are untouched: auto fill zones, auto translate, DNP
    included.
    The board itself is unchanged. The plugin refills the zones and asks to
    save, but the refill produced an identical result, so the .kicad_pcb
    differs only by timestamp.
    Checked on the regenerated output:
    positions.csv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
2026-09-20 Add the reservoir capacitors the 3.3V regulator was missing
    U7 (AMS1117-3.3) was running without an output capacitor. Its datasheet
    lists one as required, not advisory: it is part of the device frequency
    compensation. The whole +3V3 net held a single 100nF, and that one is
    the PCA9548A decoupler sitting 63 mm away on the other side of the board.
    That rail feeds seven OLED displays whose internal charge pumps draw in
    pulses, so this is the most likely cause of the freezes the unit shows
    in use. An unstable 3.3V rail corrupts I2C, and a corrupted transaction
    leaves the Wire library waiting for an ACK that never arrives: the MCU
    stays alive but never returns. That matches the symptom, a freeze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
    [FCU_Mainboard_v3.kicad_pcb, pwr_conn.kicad_sch]
2026-09-20 Restructure as the whole glareshield unit, add the five satellite boards
    This repository already held the 3D parts, the STL files and the firmware
    alongside the mainboard, so it was the unit's repository in everything but
    name. The five boards that complete the unit lived outside it with no
    version control at all. They are now in.
    Kicad Files/ -> Mainboard/ the folder name was ambiguous once six
    KiCad projects live side by side
    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
    [9V_Distribution.kicad_pcb, 9V_Distribution.kicad_sch, Backlighting_LEDModule_PCB.kicad_pcb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]
2026-09-20 Fix the swapped EFIS filenames and rename the backlight nets to +5V
    Two naming defects, no electrical change on any board.
    EFIS sheets
    -----------
    The root sheet pointed EFIS_LEFT at efis_right.kicad_sch and EFIS_RIGHT at
    efis_left.kicad_sch. The schematic was correct, since the file behind the
    LEFT sheet did hold the L_* signals, but the filenames said the opposite and
    anyone reading the files from outside KiCad would have been misled.
    The two files are swapped and every reference follows: the sheet properties
    in the root schematic and the 49 sheetfile entries the footprints carry on
    the board. Each file now matches the sheet that loads it.
    netlist 198 nets, 135 components, not one n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
    [Backlighting_LEDModule_PCB.kicad_pcb, Backlighting_LEDModule_PCB.kicad_sch, Backlighting_PCB.kicad_pcb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]
2026-09-20 Re-annotate the dimmer against its board, set the Korry resistor values
    Tidying only. No board changed, no connection moved: all six projects still
    report 0 unconnected items and 0 schematic parity issues.
    Backlighting_Dimmer was worse than the value mismatch the Readme recorded.
    Its schematic and its board disagreed on six reference designators, and
    three separate connectors in the schematic all carried J73:
    J73 -> J12, J13, J14 three connectors sharing one reference
    J12 -> J31 J12 was the potentiometer in the schematic and a
    terminal block on the board
    J93 -> J32
    U2 -> U1
    Running Update PCB from Schematic on that board would have pus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
    [Backlighting_LEDModule_PCB.kicad_sch, Backlighting_PCB.kicad_sch, KorryLargePCB_SMD.kicad_pcb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]
2026-09-20 Migrate every project to KiCad 10, add the PWR_FLAGs the LEDModule wanted
    All six projects are now KiCad 10, schematics and boards. Verified against
    the previous commit: every netlist is identical, net for net and node for
    node, and every board still reports 0 unconnected items and 0 schematic
    parity issues.
    FCU_Mainboard_v3 already 10
    9V_Distribution 9 -> 10
    Backlighting_PCB 8 -> 10
    Backlighting_LEDModule_PCB 8 -> 10
    KorryLargePCB_SMD 8 -> 10
    KorrySmallPCB_SMD 8 -> 10
    Two PWR_FLAGs on the LEDModule input, one per rail. That board is a passive
    fan-out: power arrives at J11 and leaves through twenty connectors, wi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
    [9V_Distribution.kicad_pcb, 9V_Distribution.kicad_sch, Backlighting_LEDModule_PCB.kicad_pcb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]
2026-09-21 Give the PSU buck the catch diode it never had
    The LM2596 on the 9V distribution board has been running without a
    freewheel diode. Net-(U4-OUT) held exactly two nodes, U4.2 and L1.1: the
    only Schottky on the board is D1, in series at the input as reverse
    protection. With nowhere else to go, the inductor current has been
    freewheeling through the regulator's own substrate diode, adding roughly
    0.4 W inside the package on top of its own 0.7 W. That is why the board
    works, and why it wears out.
    D2 SS54 Schottky, cathode on the switch node, anode to ground.
    C4 220uF electrolytic beside C2, to give the control loop the ESR a
    ceramic output capacitor does not provide.
    F2 MF-RHT100 -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
    [9V_Distribution.kicad_pcb, 9V_Distribution.kicad_sch]
2026-09-21 Refill the PSU ground zone
    Zones filled in Pcbnew against the new placement. DRC is back to the
    board's baseline: 16 violations, all of them library links, with 0
    unconnected items and 0 schematic parity issues. The 56 clearance, hole
    and solder-mask violations in the previous commit were the stale pour,
    as expected, and are gone.
    Object counts are unchanged either side of the save (46 tracks, 17 vias,
    22 footprints); KiCad only reordered the blocks and recomputed the fill.
    The mounting holes kept exclude_from_pos_files.
    [9V_Distribution.kicad_pcb]
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2026-09-21 Add the mainboard 9V branch to the PSU
    Second, independent regulator on the PSU so the mainboard does not share a
    rail with the PWM-switched backlighting. Tapped from D1's cathode: the
    reverse protection is shared, the fuse is not, so a fault on one branch
    does not take down the other.
    F3 0.5A polyfuse, mainboard branch only
    U1 P78A05-1000, the same module already used on RMP V5
    C5/C6, C7/C8 100nF + 100uF each side, mirroring RMP V5
    J5 screw terminal, beside J1, so both cables leave the same edge
    Nets are labelled VIN_MB and +5V_MB rather than left as Net-(U1-+VOUT).
    Layout: the whole chain sits in the y 44..56 band, which was empty. That
    band was empty of footprints but not o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
    [9V_Distribution.kicad_pcb, 9V_Distribution.kicad_sch]
2026-09-21 Enlarge the PSU to 70x80 and move the mainboard branch into the new space
    The board was 50x70 with one regulator; adding a second made it cramped
    enough that parts were clearing each other by fractions of a millimetre and
    the buck's output had to cross the new chain on the bottom layer.
    Growing right and down to 70 x 80 keeps every existing coordinate, so the
    buck section does not move. The P78A05 chain now runs vertically in the new
    strip at x 150..170, which frees the middle band again: the buck's output
    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
    [9V_Distribution.kicad_pcb]
2026-09-21 Add the mainboard supply selector to the schematic
    U8 is a TPS2115A power mux on the +5V net: IN1 from the PSU's clean 5V,
    IN2 from USB VBUS, OUT becomes the board rail. D0 is grounded and D1 comes
    from a 100k/100k divider on the incoming rail, so the choice is
    deterministic -- the external supply wins above about 4V -- rather than
    "whichever input is higher", which with two nominal 5V sources would be a
    coin toss. The part has no body diodes across its switches, so no current
    can return into the USB port. R34 sets the limit to about 0.8A.
    P1 pin 1 and R14, the D+ pull-up, move off +5V onto a new VBUS net; that is
    also more correct, since the pull-up should follow VBUS. JP1, VCC and the
    ISP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
    [pwr_conn.kicad_sch]
2026-09-21 Turn J5 round and move the PSU notes clear of the drawing
    J5 was placed with its wire entry facing C8, leaving no room for the
    cables. Rotated 180 and moved to (160, 33) so the cables leave over the
    top edge, the same way J2-J4 do. The output track follows pad 2 to its new
    position.
    The two schematic notes sat on top of each other and over U1's fields.
    They move below the drawing, which ends at y 127, and become four:
    the two supply branches, the shared reverse protection with separate
    fuses, what D2 is for, and C1's voltage rating. The old note claimed C2
    needed 25 V as well; it does not, it sits on the 5 V output.
    Includes the zone refill done in Pcbnew, which brought the board to 16
    vio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
    [9V_Distribution.kicad_pcb, 9V_Distribution.kicad_sch]
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2026-09-21 Make the PSU buck section through-hole and give it room
    D1, D2, C1 and C2 were SMD in among through-hole parts, for no better reason
    than matching what the board already had. Two of the four conversions are
    not about convenience:
    C1 sits across the 9V input and needs 25V of rating, which a 1206 MLCC of
    that capacitance does not come in. As an electrolytic the problem goes
    away instead of being documented.
    C2 is the buck's output capacitor and the LM2596 wants ESR there. As a
    ceramic it had none, which is why C4 exists; as an electrolytic it
    brings its own.
    D1 and D2 become 1N5822 on the stock Device:D_Schottky symbol, which also
    drops four missing-library warn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
    [9V_Distribution.kicad_pcb, 9V_Distribution.kicad_sch]
2026-09-21 Refill the PSU zones and drop two stray vias
    Zones refilled in Pcbnew after the through-hole conversion. That left two
    vias dangling:
    (129.0, 71.35) a stitching via for D2's old anode position. D2's anode is
    now a through-hole pad 1.3mm away that reaches both planes
    by itself, so the via has nothing to do.
    (151.0, 80.0) a ground stitching via that the re-routed 9V branch now
    runs exactly over, so KiCad had reassigned it to
    Net-(D1-K). Not a short, but a pointless hole in the
    ground plane.
    Both removed. The board is now at 12 violations, all library links: three
    LED footprints from the missing A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
    [9V_Distribution.kicad_pcb]
2026-09-21 Give the USB-side power nets a netclass of their own
    VBUS and 5V_EXT were on Default, which means 0.2mm track. VBUS carries the
    whole board's current whenever it runs off USB -- about 330mA -- and the
    autorouter would have used the netclass width. A new USB5V class gives them
    1.0mm, matching what +5V already gets.
    Clearance stays at 0.1mm, the Default value, rather than the 0.2mm the 5V
    class uses, so nothing already routed is affected.
2026-09-21 Close the +5V link between the board and the selector strip
    The net was in two pieces: everything on the board in one, and U8 pin 7 with
    C27 in the other, 53mm apart. The ratline for it starts at x 280, inside the
    20mm added today, which is why it was easy to miss on screen.
    Routed from C5 pin 1 at (224.34, 95.90) along the bottom edge to C27 pin 1.
    The two vertical legs are on the back because the front is blocked at both
    x 228 and x 279; the long horizontal stays on the front at y 118, so the
    bottom plane takes two short slots instead of one 85mm one. Four vias.
    Every leg was checked against all other-net copper before being written:
    the tightest is 0.50mm, at C5's own ground pad, agains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
    [FCU_Mainboard_v3.kicad_pcb]
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2026-09-21 Refill the zones and refresh the PSU footprints
    Mainboard: riempimento rifatto sulle piste da 1 mm. Le 12 clearance verso
    la zona GND erano solo il riempimento vecchio e sono sparite. 164 isole,
    nessuna orfana: allargare non ha strozzato il piano da nessuna parte.
    PSU: aggiornati i footprint dalla libreria. Le 9 lib_footprint_mismatch
    sono sparite, restano le 3 sui LED, che dipendono dalla libreria
    PCM_LED_SMD_AKL non installata. I valori sul serigrafico hanno retto
    l'aggiornamento: tutti e 14 ancora su F.Silk e nessuno finito sopra a un
    pad o a un'altra scritta.
    Mainboard: 0 violazioni, 0 scollegamenti, 0 parita'.
    PSU: 3 violazioni di libreria, 0 scollegamenti, 0 parita'.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
    [9V_Distribution.kicad_pcb, FCU_Mainboard_v3.kicad_pcb]
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2026-09-22 Refill the dimmer ground zone after the terminal swap
    Sul dimmer le dieci violazioni di rame erano tutte il riempimento vecchio,
    calcolato sui pad dei morsetti prima dello spostamento: ognuna nominava
    Zone [GND] e parecchie stavano a 0.497 contro i 0.5 richiesti. Rifatto il
    riempimento spariscono.
    Il LEDModule zone non ne ha, quindi li' il salvataggio non ha ricalcolato
    niente: KiCad ha solo riscritto gli uuid.
    Verificato che il salvataggio non abbia toccato altro: piste, componenti e
    via sono identici su entrambe le schede, 86 e 128 tratti, stessi estremi,
    stesse larghezze, stesse posizioni.
    Dimmer: 11 violazioni, 10 di libreria piu' l'avviso serigrafico su J32.
    LEDModule: 2, entrambe di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
    [Backlighting_LEDModule_PCB.kicad_pcb, Backlighting_PCB.kicad_pcb]
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2026-09-22 Fill in the missing 3D models
    Le ricostruzioni 3D avevano undici buchi. Sette si chiudono con modelli che
    KiCad ha gia' installati, senza scaricare niente.
    Tre non avevano proprio un modello, perche' il footprint viene da una
    libreria di terzi che non ne porta, ma l'involucro e' standard:
    U5 ATMega2560 TQFP-100_14x14mm_P0.5mm
    I2C_1 PCA9548APW TSSOP-24_4.4x7.8mm_P0.65mm
    S1 pulsante SW_PUSH_6mm
    Il P78A05 aveva un footprint fatto in casa, e i suoi tre pad stanno a (0,0),
    (2.54,0) e (5.08,0): identici a quelli del RECOM R-78E, che e' lo stesso
    genere di mattoncino SIP-3 e ha il suo modello. Preso quello.
    Il 555 sul dimmer puntava a un .wrl e a una variabile che KiCad 1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
    [9V_Distribution.kicad_pcb, Backlighting_PCB.kicad_pcb, FCU_Mainboard_v3.kicad_pcb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]
2026-09-22 Correct the note on the missing 3D models
    Erano cinque, ora sono tre: i due polyfuse Bourns e il toroide sulla PSU,
    piu' P1 sulla mainboard. Aggiunto perche' non si riempiono, e quali dei
    modelli nuovi sono equivalenti di involucro e non lo stesso codice.
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2026-09-22 Replace the stale firmware fork with elral v1.0.1, rebranded SF_FCU
    What was under VsCode Files was a fork taken in April 2024 and last built
    in November 2024, before the board was finished. It is not what runs on the
    unit: the live tree is a clone of elral/MF_FCU_EFIS_OLEDs, and MobiFlight
    here has the upstream Community package installed, not this one. Keeping a
    dead copy next to the KiCad project is a trap, so it is replaced by the
    firmware that actually flies.
    This is elral v1.0.1 with two changes and nothing else. The device is named
    SF_FCU, following the pattern already used for SF_RMP and SF_OVHD, so it can
    sit beside the upstream one in the Community folder. And the two EFIS
    multipl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
2026-09-22 Follow MobiFlight's own template: core firmware 3.1.4
    The reference for this project is the MobiFlight base firmware, not elral's
    fork, so the scaffolding now comes from MobiFlight/CommunityTemplate, which
    pins core 3.1.4. That is a major version up from the 2.5.1 the old tree sat
    on, and the custom device API moved with it:
    - attach() takes a fourth argument, configFromFlash, and bails out when
    adrPin is zero
    - getStringFromEEPROM() became getStringFromMem(), which reads either the
    EEPROM or a config baked into flash, and bounds-checks both
    - FitInMemory() no longer exists; allocation goes through MF_ALLOC_TYPE and
    is checked for null. Both OLEDInterface and FCU_EFIS::attach used the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
    [FCU_EFIS.cpp, MFCustomDevice.cpp, OLEDInterface.h]
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2026-09-23 Make the seven display blocks in begin() alike
    The two EFIS blocks had drifted from the five FCU ones. The right one set the
    text colour and both pushed a frame before drawing, none of which survives:
    the updateDisplay* call that follows clears the buffer, sets the colour and
    displays again by itself. The left block's banner had also been left with
    doubled slashes by someone who commented it out and put it back by hand.
    Also drops a stray "send in ASCII" comment, which was the last thing telling
    updateDisplayEfisLeft and updateDisplayEfisRight apart. They are now the same
    function but for the channel constant and the variables they read.
    No behaviour change. Flash drops 32 bytes and two bl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
    [FCU_EFIS.cpp]
2026-09-23 Take the heap out of the redraw path, and the unused device families out of the build
    Three things, none of which changes what appears on the displays.
    The nine Connector values were Arduino Strings. Each one held a heap block,
    and three more were allocated and freed on every redraw, which is how an AVR
    ends up fragmented and falling over at hour three rather than minute one.
    They are fixed buffers now, zero filled by setValue() because the padding
    code deliberately reads past the end of a value and expects 0 there, which is
    what String::operator[] used to hand back. Static RAM went UP by 18 bytes,
    nine 6-byte objects becoming nine 8-byte buffers; that was never the point.
    The only allocati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
    [FCU_EFIS.cpp, FCU_EFIS.h, OLEDInterface.h]
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2026-09-23 Do not let a stray space from the shell into the firmware filename
    The readme told you to build with 'set VERSION=1.1.0 && pio run' from cmd.exe.
    cmd assigns everything between the = and the &&, so VERSION became '1.1.0 '
    and the build wrote SF_FCU_mega_1_1_0 .hex while board.json asked for
    SF_FCU_mega_1_1_0.hex. MobiFlight could not find the firmware and refused to
    install it.
    The command is corrected to set "VERSION=1.1.0", but relying on getting the
    quoting right is not a fix, so get_version.py and copy_fw_files.py now strip
    the value they read from the environment. Verified by building with a trailing
    space deliberately: the hex comes out clean and matches what board.json asks
    for. This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
2026-09-23 Record the Fabrication Toolkit settings as the plugin now writes them
    The plugin was updated and rewrote its options file on all four boards that
    have one. It added ARCHIVE_NAME, OPEN BROWSER and BACKUP_OPT, and flipped
    ALL_ACTIVE_LAYERS from true to false, which decides how many layers end up in
    the ZIP handed to JLCPCB. Worth having in the history rather than as an
    untracked surprise, since the next thing to happen is an order.
